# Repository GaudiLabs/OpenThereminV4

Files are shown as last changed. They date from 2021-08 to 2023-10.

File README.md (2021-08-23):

# OpenThereminV4
Open Source Theremin Instrument

Schematics, printed circuit board (PCB) design, bill of materials (BOM) and Arduino UNO compatible software for the OpenTheremin V4

### Open Source Theremin based on the Arduino Platform

OpenTheremin is an arduino based real Therein instrument. The legendary music instrument was invented by Leon Theremin back in 1920. The theremin is played with two antennas, one to control the pitch and one for volume. The electronic shield with two ports to connect those antennas comprises two heterodyne oscillators to measure the distance of the hand to the antenna when playing the instrument. The resulting signal is fed into a AtMega328P microcontroller. After linearization and filtering the circuit generates the instruments sound that is then played through a high quality digital analog audio converter on the board. The characteristics of the sound can be determined by a wave table on the arduino.

For more info on the open source project and on availability of ready made shield see:

http://www.gaudi.ch/OpenTheremin/

### Installation
1. Open up the Arduino IDE
2. Open the File "Open_Theremin_V4.ino"
3. Selecting the correct usb port on Tools -> Serial Port
4. Select the correct arduino board from Tools -> Board
5. Upload the code by clicking on the upload button.

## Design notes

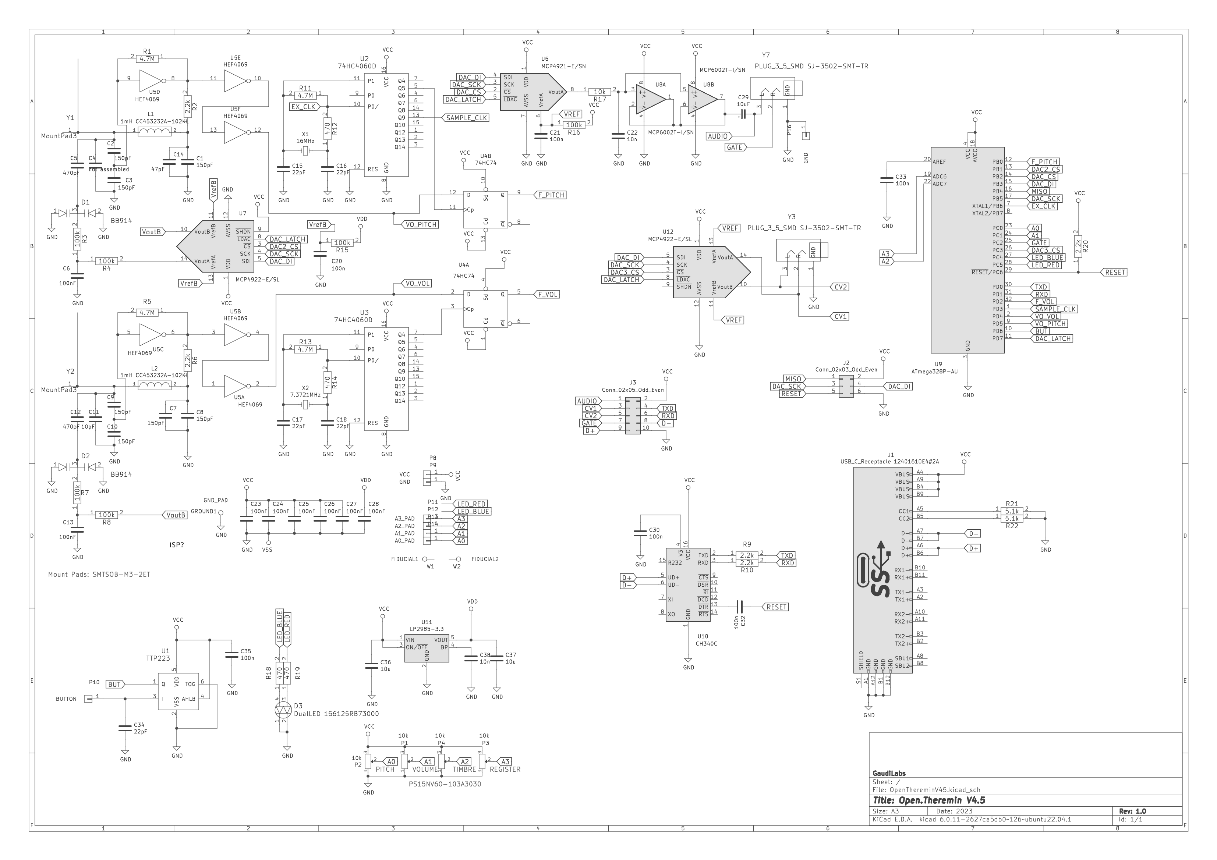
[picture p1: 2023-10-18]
Electronics/OpenThereminV45_Schematic.png

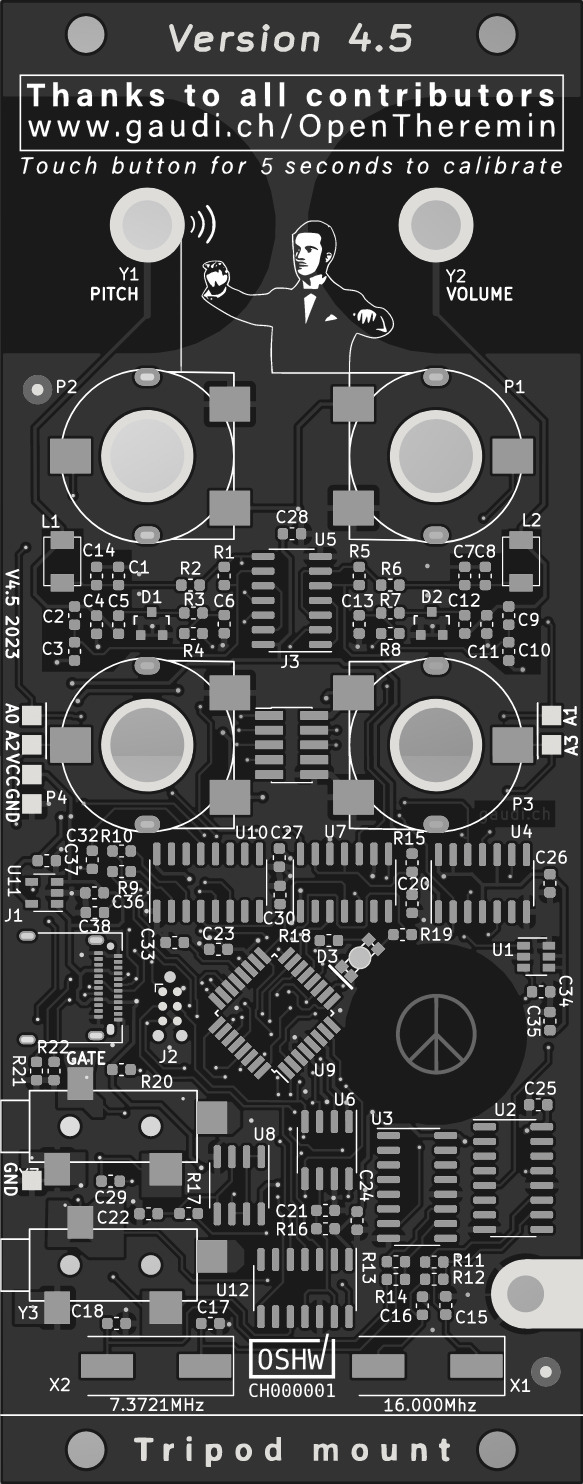
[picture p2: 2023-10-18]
Electronics/OpenThereminV45_PCB_back.png

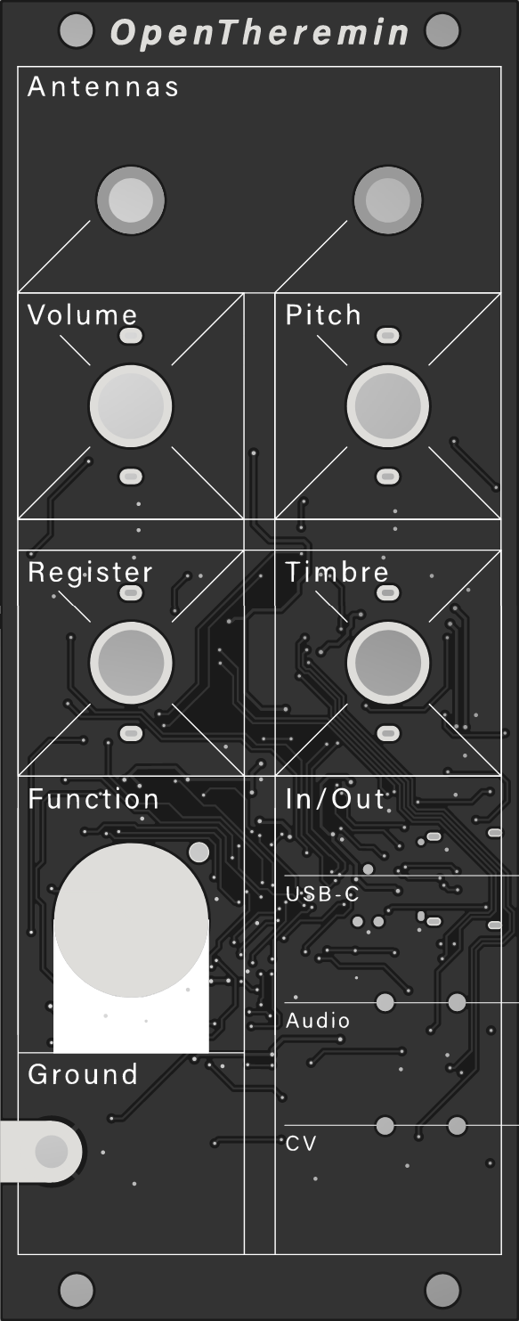
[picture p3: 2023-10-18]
Electronics/OpenThereminV45_PCB_front.png

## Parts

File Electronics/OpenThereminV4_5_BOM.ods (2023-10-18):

 |  |  | OpenTheremin V4.5 BOM (Bill of Materials)
 |  |  |  |  |  | August 5, 2023
Item # | *Ref Des | *Qty | Manufacturer | *Mfg Part # | Description / Value | *Package | Type | Your Instructions / Notes
1 | U1 | 1 | TonTek | TTP223E-BA6 | TonTouch, key touch pad detector IC | SOT-23-6 | SMD
2 | U2,U3 | 2 | Nexperia | 74HC4060D | 14-STG RC BINARY COUNTER | SOIC-16_N | SMD
3 | U4 | 1 | Nexperia | 74HC74D | Flip-Flops DUAL D-TYPE POSITIVE EDGE-TRIG | SOIC-14_N | SMD
4 | U5 | 1 | Nexperia | HEF4069UBT | HEX INVERTER | SOIC-14_N | SMD
5 | U6 | 1 | Microchip Technology | MCP4921T-E/SN | DAC Sgl 12-bit SPI int | SOIC-08_N | SMD
6 | U7, U12 | 2 | Microchip Technology | MCP4922T-E/SL | DAC Dual 12-bit SPI int | SOIC-14_N | SMD
7 | U8 | 1 | Microchip Technology | MCP6002T-I/SN | OpAmp Dual 1.8V 1MHz | SOIC-08_N | SMD
8 | U9 | 1 | Microchip Technology | ATMEGA328P-AU | 8-bit Microcontrollers - MCU 32KB, 20MHz 1.8V-5.5V | TQFP-32_7x7mm_P0.8mm | SMD
9 | U10 | 1 | ETC | CH340C | USB to serial chip | SOIC-16_3.9x9.9mm_P1.27mm | SMD
10 | U11 | 1 | Texas Instruments | LP2985-33DBV | LDO Voltage Regulators 3.3V, 150-mA Low-Noise | SOT-23-5 | SMD
11 | D1,D2 | 2 | Infineon Technologies | BB 914 E6327 | Varactor Diodes 50mA Silicn Variable Capacitance Diode | SOT-23 | SMD
12 | D3 | 1 | Wurth Elektronik | 156125RB73000 | Reverse SMD BiColor LED Blue / Red, WL-SBRW | DualLED | SMD
13 | X1 | 1 | any | Crystals 16.000MHz +/-30ppm 18pF | Crystals | Crystal_HC49-SD_SMD 13.4 x 4.9 x 4.3mm | SMD
14 | X2 | 1 | any | Crystals 7.37280MHz +/-30ppm 18pF | Crystals | Crystal_HC49-SD_SMD 13.4 x 4.9 x 4.3mm | SMD
15 | L1,L2 | 2 | Bourns | CC453232A-102KL | Coil, 1mH UH 10%, 40 Ohms | COIL | SMD
16 | C1,C2,C3,C9,C10,C7,C8 | 7 | any | 150pF 50V NPO 5% | Capacitor | 603 | SMD | MUST BE C0G (NP0)
17 | C5,C12 | 2 | any | 470pF 50V NPO 5% | Capacitor | 603 | SMD | MUST BE C0G (NP0)
18 | C22,C38 | 2 | any | 10nF 16 V X7R 5% | Capacitor | 603 | SMD
19 | C6,C13,C20,C21,C23, C24,C25,C26,C27,C28,C30,C32,C33,C35 | 14 | any | 100nF 25V X7R 10% | Capacitor | 603 | SMD
20 | C29,C36,C37 | 3 | any | 10uF 6.3V X5R 10% | Capacitor | 603 | SMD
21 | C14 | 1 | any | 47pF 50V NPO 5% | Capacitor | 603 | SMD | MUST BE C0G (NP0)
22 | C11 | 1 | any | 10pF 50V NPO 5% | Capacitor | 603 | SMD | MUST BE C0G (NP0)
23 | C4 | 0 | any | NOT ASSEMBLED |  | 603 | SMD
24 | C15,C16,C17,C18,C34 | 5 | any | 22pF 16 V X7R 5% | Capacitor | 603 | SMD | MUST BE C0G (NP0)
25 | R1,R5,R11,R13 | 4 | any | 4.7M OHM 1% | Resistor | 603 | SMD
26 | R12,R14,R18,R19 | 4 | any | 470 OHM 1% | Resistor | 603 | SMD
27 | R17 | 1 | any | 10K OHM 1% | Resistor | 603 | SMD
28 | R3,R4,R7,R8,R15,R16 | 6 | any | 100K OHM 1% | Resistor | 603 | SMD
29 | R2,R6,R9,R10,R20 | 5 | any | 2.2k OHM 1% | Resistor | 603 | SMD
30 | R21,R22 | 2 | any | 5.1k OHM 1% | Resistor | 603 | SMD
31 | Y3, Y7 | 2 | CUI Devices | SJ-3524-SMT-TR | Phone Connectors Audio Jacks, 3.5mm SMD | PLUG3_5_SMD | SMD
32 | P1,P2,P3,P4 | 4 | Amphenol Piher | PS15NV60-103A3030-PM | SMD POT 10K OHM LINEAR | SMD POT | SMD
33 | J1 | 1 | Amphenol Commercial Products | 12401610E4#2A | USB_C_Receptacle_Amphenol_12401610E4-2A | USB_C_Receptacle | SMD
34 | J3 | 1 | Amphenol FCI | 20021521-00010C1LF | 10 Pos, 1.27 MM BTB HEADER SMT TYPE SHROUD | SMD Receptacle | SMD
35 | Y1, Y2 | 2 | PEM | SMTSO-M3-3ET | BRASS SMT STANDOFF M3 L:3MM | Hardware | SMD

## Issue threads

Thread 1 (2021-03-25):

More flexibility on USB/Serial interface design could be nice

MrDham, 2021-03-25:
Hello Urs,

I had a look at this new theremin schematic. It is a very nice idea to merge arduino and schield board in a single one.

I hope that I don't bother you in a too much early or too much late stage of the development, I have just one comment:

As CH340G can't be re-programmed into a MIDI USB port, in order to allow implementation of some additionnal material for a MIDI interface (MIDI DIN connector, ... ), an additionnal free solder pad on TXD could be very nice to have.

Regards

MrDham, 2021-09-10:
It seem that this issue is fixed, isn't it ?

In most recent design, I can see that a new pad is connected to RXD of CH340G wich is equivalent to TXD of ATMEGA 328P -> correct :+1:

GaudiLabs, 2021-12-09:
Yes, we can now do MIDI over serial and real MIDI connector to TX pad.

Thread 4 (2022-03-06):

PCB file is inconsistent with GBR file.

ws786873, 2022-03-06:
PCB file is inconsistent with GBR file. I want to use PCB file to generate SMT positioning, but it seems that PCB file is a semi-finished product. 0603 is a little difficult for me.

GaudiLabs, 2022-03-06:
Hi
Before just accusing me of publishing unfinished files, please tell me who you are and how you can contribute in joining this project. Then please be  specific enough for me to see where you ran into problems. If you just want a working theremin you can buy it here:

gaudishop.ch

Best,
Urs

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
🧪 GaudiLabs LLC
Urs Gaudenz
Email: ***@***.***
www.gaudi.ch

ws786873, 2022-03-06:
Sorry, I just want to make one. I can't seem to contribute anything to the project. Sorry again.

GaudiLabs, 2022-03-06:
The files are designed on the open design software KiCad. You can export Gerber files from thete. If you see inconsistencies with the repo files,  please regenerate the gerber files and fix that
Urs

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
🧪 GaudiLabs LLC
Urs Gaudenz
Email: ***@***.***
www.gaudi.ch

Closed 2022-03-07.

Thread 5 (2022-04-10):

SPI bus breakout

Semptum, 2022-04-10:
Hi,
Is there a place where one can plug onto the SPI bus?
Looking at the PCB layout in KiCAD I can't find a practical place where I could connect something.
I'm looking to add Bluetooth functionality so I thought I would add a secondary board with an ESP32 and a small screen to be able to connect to headphones/speakers and establish an A2DP stream.
Is there a better way to connect the two than soldering a wire onto the atmega's pads?
Best regards

Semptum, 2022-04-10:
Looking more carefully at the schematic (hardware is not my forte), I

Closed 2022-04-10.

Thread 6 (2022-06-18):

Missing technical drawing

8bignic8, 2022-06-18:
Hey, it would be amazing if you could add the scamatics aka the position of all the knobs and so on as a pdf, because I want to make a Kase with a midi output for the teremin. I could mesaure it but I think it would be better if I had the  korrekt positions :).

If it is not possible that is also ok, but it would be a nice to have for the case design :)

greetings nice project

Closed 2023-03-08.

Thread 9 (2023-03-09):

ATmega fuses setting

roman-dvorak, 2023-03-09:
Hello,
is known the correct setting of ATmega fuses? It would be useful to describe it somewhere.

Thank you

GaudiLabs, 2023-03-09:
FUSES

EXTENDED FUSE BYTE (EFUSE):  0xFD
HIGH FUSE BYTE:  0xDE
LOW FUSE BYTE: 0xFF

(Same as Arduino UNO.)

Closed 2023-03-09.

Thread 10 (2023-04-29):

Trouble uploading sketch from Arduino IDE

thedeany, 2023-04-29:
I'm trying to upload a new version to the theremin I just received last week (I'm trying the MIDI implementation, but this issue also occurs if I try to upload the standard version as in this repo), and I'm getting the following error message.
```
Sketch uses 27082 bytes (83%) of program storage space. Maximum is 32256 bytes.
Global variables use 362 bytes (17%) of dynamic memory, leaving 1686 bytes for local variables. Maximum is 2048 bytes.
avrdude: stk500_recv(): programmer is not responding
avrdude: stk500_getsync() attempt 1 of 10: not in sync: resp=0x00
avrdude: stk500_recv(): programmer is not responding
avrdude: stk500_getsync() attempt 2 of 10: not in sync: resp=0x00
avrdude: stk500_recv(): programmer is not responding
avrdude: stk500_getsync() attempt 3 of 10: not in sync: resp=0x00
avrdude: stk500_recv(): programmer is not responding
avrdude: stk500_getsync() attempt 4 of 10: not in sync: resp=0x00
avrdude: stk500_recv(): programmer is not responding
avrdude: stk500_getsync() attempt 5 of 10: not in sync: resp=0x00
avrdude: stk500_recv(): programmer is not responding
avrdude: stk500_getsync() attempt 6 of 10: not in sync: resp=0x00
avrdude: stk500_recv(): programmer is not responding
avrdude: stk500_getsync() attempt 7 of 10: not in sync: resp=0x00
avrdude: stk500_recv(): programmer is not responding
avrdude: stk500_getsync() attempt 8 of 10: not in sync: resp=0x00
avrdude: stk500_recv(): programmer is not responding
avrdude: stk500_getsync() attempt 9 of 10: not in sync: resp=0x00
avrdude: stk500_recv(): programmer is not responding
avrdude: stk500_getsync() attempt 10 of 10: not in sync: resp=0x00
Failed uploading: uploading error: exit status 1
```

I am selecting `Arduino Uno` from the boards list in the IDE, and as far as I am aware a "Programmer" does not need to be selected/the programmer choice doesn't matter in this case.

I have updated to the latest version of the IDE, I have tried multiple USB cables and ports, and I've searched for general solutions to this `avrdude` error, and nothing fixes the issue. Do I need to burn a new bootloader or something? I'm not sure exactly what the process looks like if so.

Any assistance would be appreciated!

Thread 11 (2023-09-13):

Problem with a capacitor in the BOM

emilien-g, 2023-09-13:
Hi,
I think there's maybe a mistake in the BOM
On line 31, for "C15,C16,C17,C18,C19,C31,C34", it's written both "22pF 16 V X7R 5%" and "MUST BE C0G (NP0)"
Thanks a lot for your work !

krokosik, 2024-08-12:
@GaudiLabs @emilien-g I want to order the capacitor, but I'm not sure which variant is right. Which is it?

krokosik, 2024-08-12:
From what I can see in the schematic, these are used for decoupling near the the button, while the others form Pierce Oscillators together with the crystals. I am no expert in audio, but from what I now the C0G are only needed in the LC oscillator, and for the aforementioned applications, the cheaper X7R is sufficient.

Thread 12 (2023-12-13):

Volume ist crcking or bounceing

Kachelhaus, 2023-12-13:
I hear a cracking sound when I mute or unmute the sound and when I increase the volume with the antenna. It is at the point where the volume increases.

GaudiLabs, 2023-12-14:
This might be due to the gate signal on the second audio channel. You can use a mono cable or deactivate the gate signal in the code before uploading.

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
🧪 GaudiLabs LLC
Urs Gaudenz
Email: ***@***.***
www.gaudi.ch

Kachelhaus, 2023-12-14:
Thank you very much,

I overlooked the fact that the gate signal is on the second channel.

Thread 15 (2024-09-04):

tonal distribution

twentyfortysix, 2024-09-04:
Hi, sorry for the question in the issues.. but might be something useful.

Is it possible to define the tonal distribution across the pitch range?

scenario:
The lower tones are bigger therefore has wider hand movement range while the high tones are getting closer and closer and are harder to play as the distance between them is getting smaller.
What would be useful would be to have a chance to alter the values so that the lower tones are closer than are by default and the higher tones are further form one another than are by default.
It might be on a software side as function that would adjust the incoming pitch value by a factor value, the value distribution

python example
```
import numpy as np

def exponential_distribution(arr, factor=1.0):
    """
    Adjust the distribution of numbers in an array to follow an exponential curve.

    Parameters:
    arr (list of float): The input array of numbers.
    factor (float): The factor controlling the steepness of the exponential curve.
                    Values > 1.0 make the curve steeper, values < 1.0 make it shallower.

    Returns:
    list of float: The adjusted array of numbers following an exponential distribution.
    """
    if len(arr) < 2:
        return arr  # No adjustment needed for arrays with less than 2 elements

    # Normalize the input array to the range [0, 1]
    normalized_arr = np.linspace(0, 1, len(arr))

    # Apply the exponential transformation
    exp_arr = (np.exp(normalized_arr * factor) - 1) / (np.exp(factor) - 1)

    # Scale the exponential array back to the original range
    min_value = arr[0]
    max_value = arr[-1]
    adjusted_arr = min_value + exp_arr * (max_value - min_value)

    return adjusted_arr.tolist()

# Example usage
original_array = [0, 1, 2, 3, 4, 5, 6, 7, 8, 9]
factor = 2.0  # Increase the steepness of the exponential curve
adjusted_array = exponential_distribution(original_array, factor)
print("Original array:", original_array)
print("Adjusted array:", adjusted_array)
```

result
```
Original array: [0, 1, 2, 3, 4, 5, 6, 7, 8, 9]
Adjusted array: [0.0, 0.3505431453935727, 0.7883185560546282, 1.3350338825354344, 2.017798699676874, 2.870468769358103, 3.935324821511089, 5.265169097891943, 6.9259436183985335, 9.0]

```

see the value distribution changes across the range, and that what is needed.
The Open theremin would have either a function with a factor value we can change as a number or the better a knob that would allow us to alter the distribution.

As that is the killer feature the PRO Moog theremins used to have, which makes them way more playable as the high notes thanks to the altered pitch value were easier to be played.

twentyfortysix, 2024-09-05:
Completed?
how is that completed? Would be nice to know how it is implemented if that is implemented already.

GaudiLabs, 2024-09-05:
Hi

Thanks for sharing your thoughts for a tonal distribution feature. The micro-controller on the current version is quite loaded already and I don't think it could do the necessary calculations fast enough. You could try of course :-). However I am collecting ideas for a next version with a more speedy processor and will for sure keep this in mind.

Best,
Urs

twentyfortysix, 2024-09-05:
Hi Urs
Just an idea, kinda brute force. What about using the mapping array, similar to wavetable.
Actual value would simply by mapped to whatever is in the mapping array. That way there will be no calculation..

Although it seems that one value processing should not be that expensive.

I have checked the code a bit and it looks like you have some pitch factors already
https://github.com/GaudiLabs/OpenThereminV4/blob/main/Software/Open_Theremin_V4/application.h
the HZ_ADDVAL_FACTOR looks like it would do the trick actually (application.cpp).

```
void Application::hzToAddVal(float hz)
{
  setWavetableSampleAdvance((uint16_t)(hz * HZ_ADDVAL_FACTOR));
}
```

here is a modified version with a exponential factor in the play

```
// Define the exponential factor
const float EXPONENTIAL_FACTOR = 2.0f; // Example value, adjust as needed

void Application::hzToAddVal(float hz)
{
  // Apply exponential transformation
  float transformedHz = pow(hz, EXPONENTIAL_FACTOR);

  // Calculate the sample advance value using the transformed frequency
  setWavetableSampleAdvance((uint16_t)(transformedHz * HZ_ADDVAL_FACTOR));
}
```
see it is easy ;) One variable and here we go, a flexible tonal distribution adjustment I have never been able to adjust on the Moog :)

Well Once the unit arrives I'll give it a go and will fiddle around with the code try what I can do about it.

Btw. I really like the Open theremin Idea and I feel like it is the actual utmost Theremin out there with lot of potential with all the flexibility thanks to the open code.

Closed 2024-09-05.

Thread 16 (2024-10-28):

documentation fault

twentyfortysix, 2024-10-28:
Hi,. sorry to make this as an issue but your captcha on the website correctly recognized me as a robot and a haven't been able to send you this over the form..

There is a wrong link to a wrong cable
https://www.gaudi.ch/OpenTheremin/index.php/opentheremin-v4/midi-interface
which points to a cable with larger pin spacing
https://www.conrad.com/en/p/bkl-electronic-10120668-ribbon-cable-contact-spacing-2-54-mm-10-x-0-08-mm-grey-1-pc-s-2103794.html

While the spacing should be a 1.27mm
something like that maybe https://www.tme.eu/cz/en/details/mikroe-1766/development-kits-accessories/mikroe/flat-cable-with-idc10-1-27mm-pitch-conne/

I just order 2 wrong batch of the cables and I feel I'm not alone :)

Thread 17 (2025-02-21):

hacking away the pitch calculation

tgirod, 2025-02-21:
Hey there. I'm trying to alter the code so the theremin plays on a hard-coded scale, and looking for advices.

Reading the code, I think I should patch something [around here](https://github.com/GaudiLabs/OpenThereminV4/blob/6819b4729de6e0845c20cc2e50181e822b74e7c8/Software/Open_Theremin_V4/application.cpp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)

What I understand from this

        tmpPitch = ((pitchCalibrationBase - pitch_v) + 2048 - (pitchPotValue << 2));
        tmpPitch = min(tmpPitch, 16383);  // Unaudible upper limit just to prevent DAC overflow
        tmpPitch = max(tmpPitch, 0);      // Silence behing zero beat
        setWavetableSampleAdvance(tmpPitch >> registerValue);
        if (tmpPitch != pitch_p)
        { // output new pitch CV value only if pitch value changed (saves runtime resources)
          pitch_p = tmpPitch;

Pitch value is read from the antenna, then recalibrated, then used to move a pointer forward in a wave table.

`tmpPitch` value is bounded to `[0;16383]` after it has been recalibrated, and [hzToAddVal](https://github.com/GaudiLabs/OpenThereminV4/blob/6819b4729de6e0845c20cc2e50181e822b74e7c8/Software/Open_Theremin_V4/application.cpp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) method suggests that it corresponds to a frequency range `[0;7809]` (divinding by HZ_ADDVAL_FACTOR).

Do I understand this correctly?

Now, I'm not sure I understand how your timing works here. I don't see any interrupt, only `mloop` running at full speed. Does it means that adding some branching inside the loop (to compute the wanted pitch) will affect the loop speed, hence the pitch?

Thanks in advance for your insights.

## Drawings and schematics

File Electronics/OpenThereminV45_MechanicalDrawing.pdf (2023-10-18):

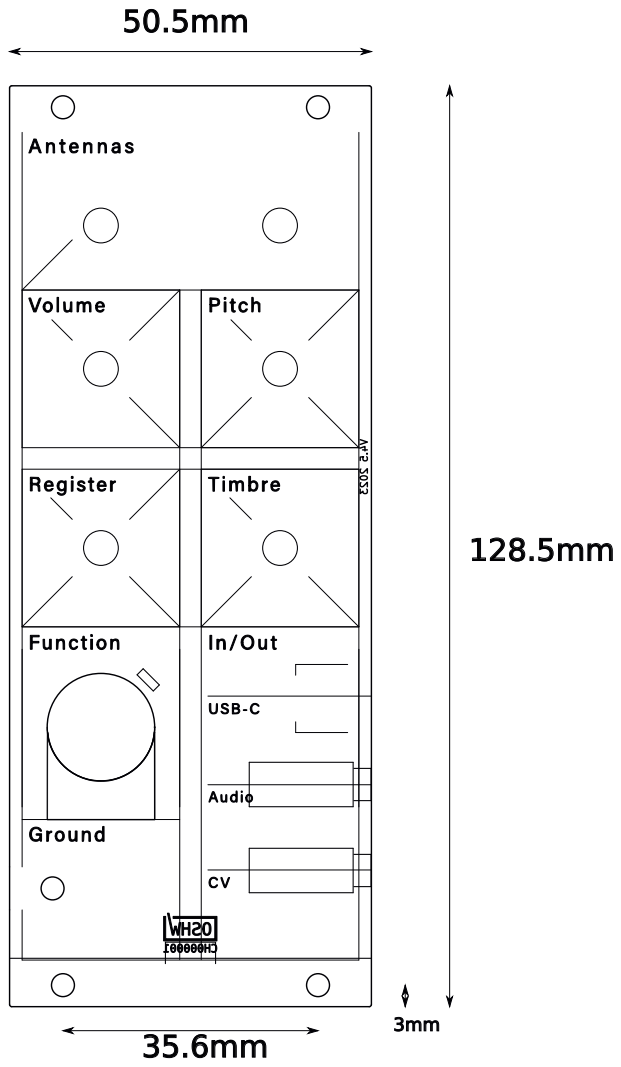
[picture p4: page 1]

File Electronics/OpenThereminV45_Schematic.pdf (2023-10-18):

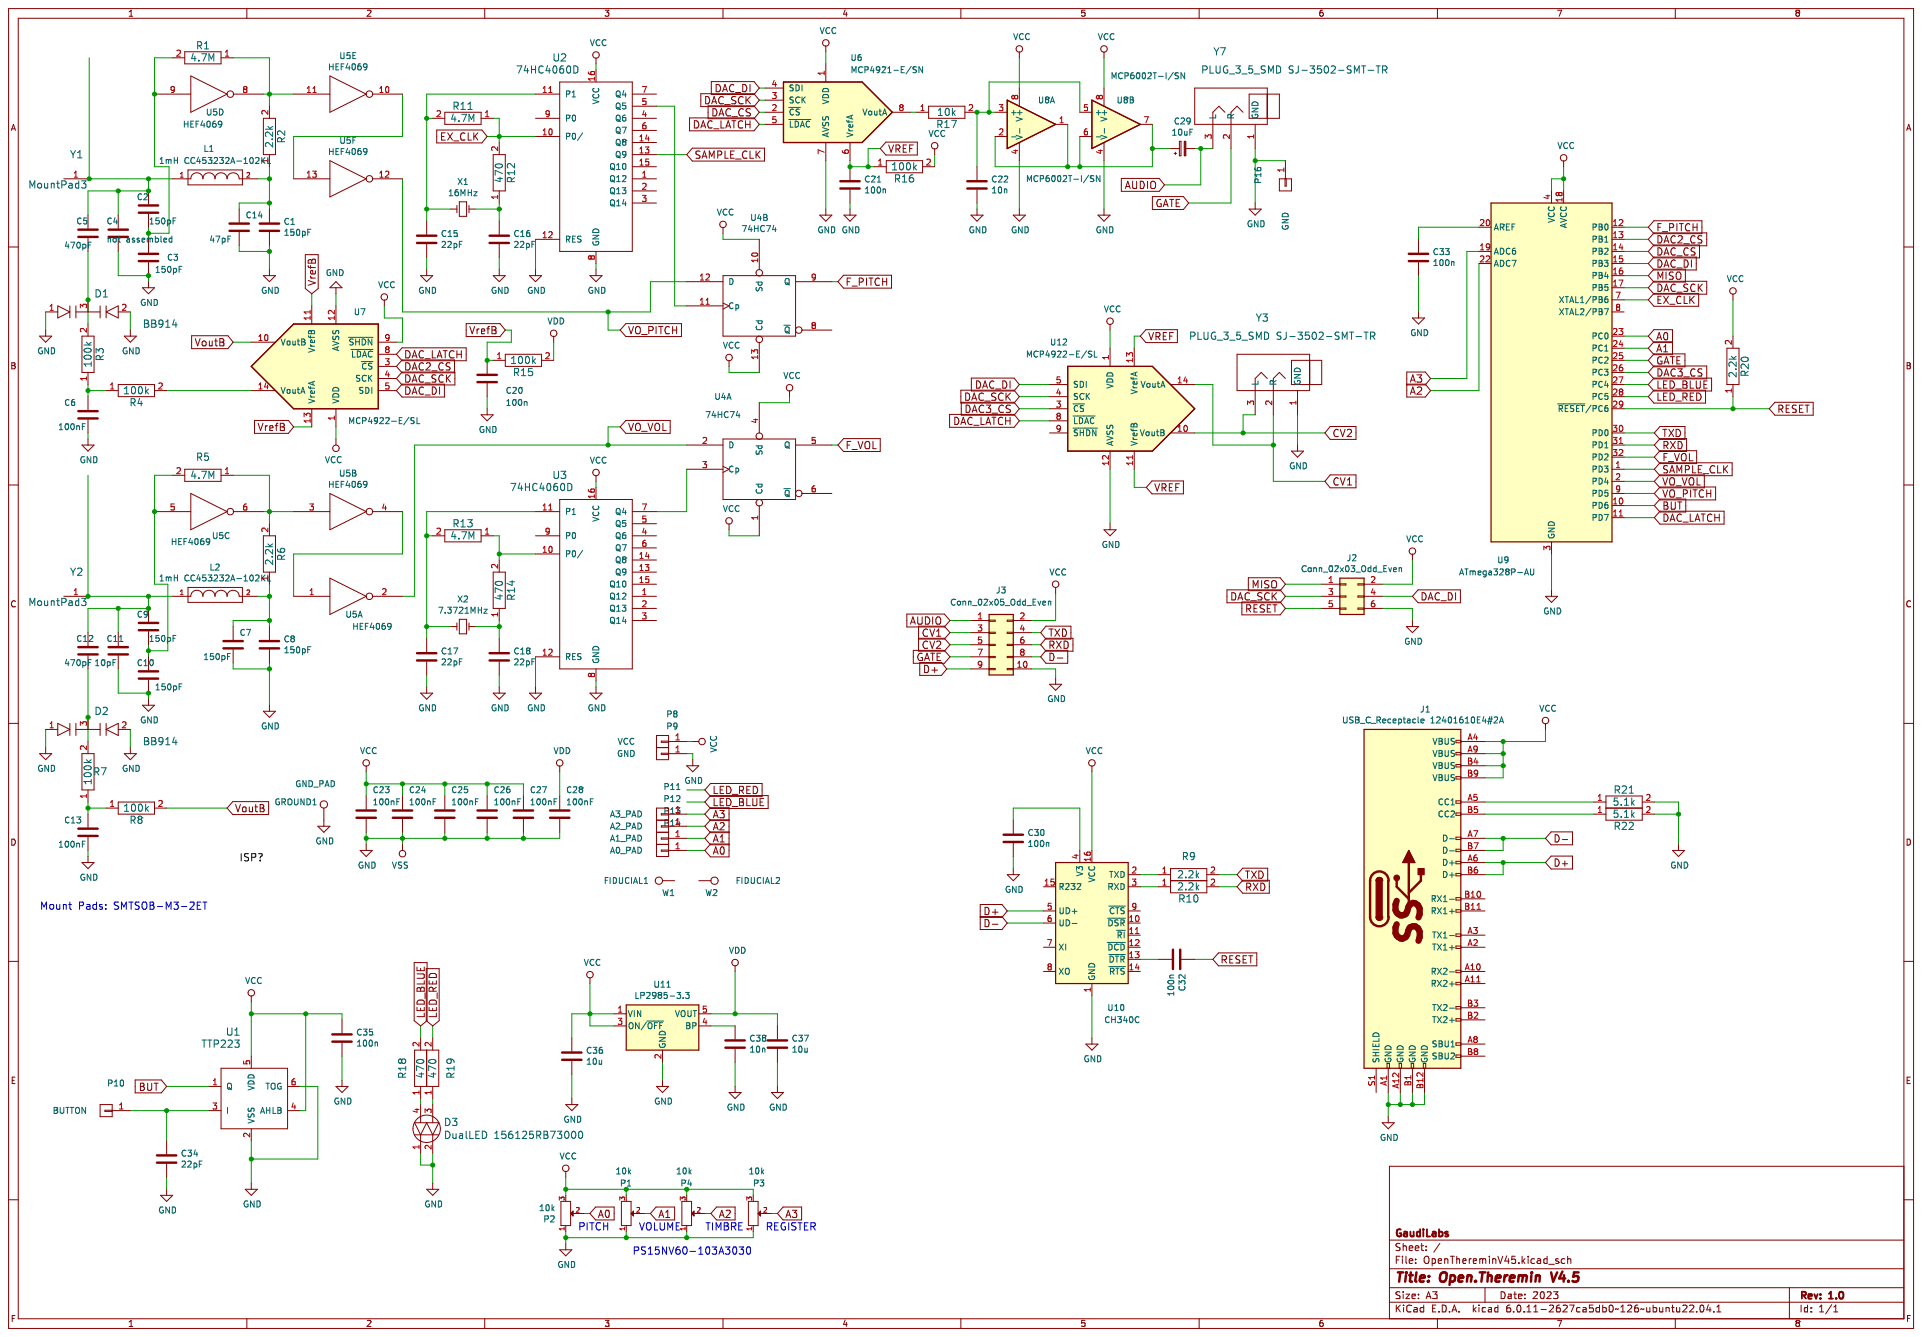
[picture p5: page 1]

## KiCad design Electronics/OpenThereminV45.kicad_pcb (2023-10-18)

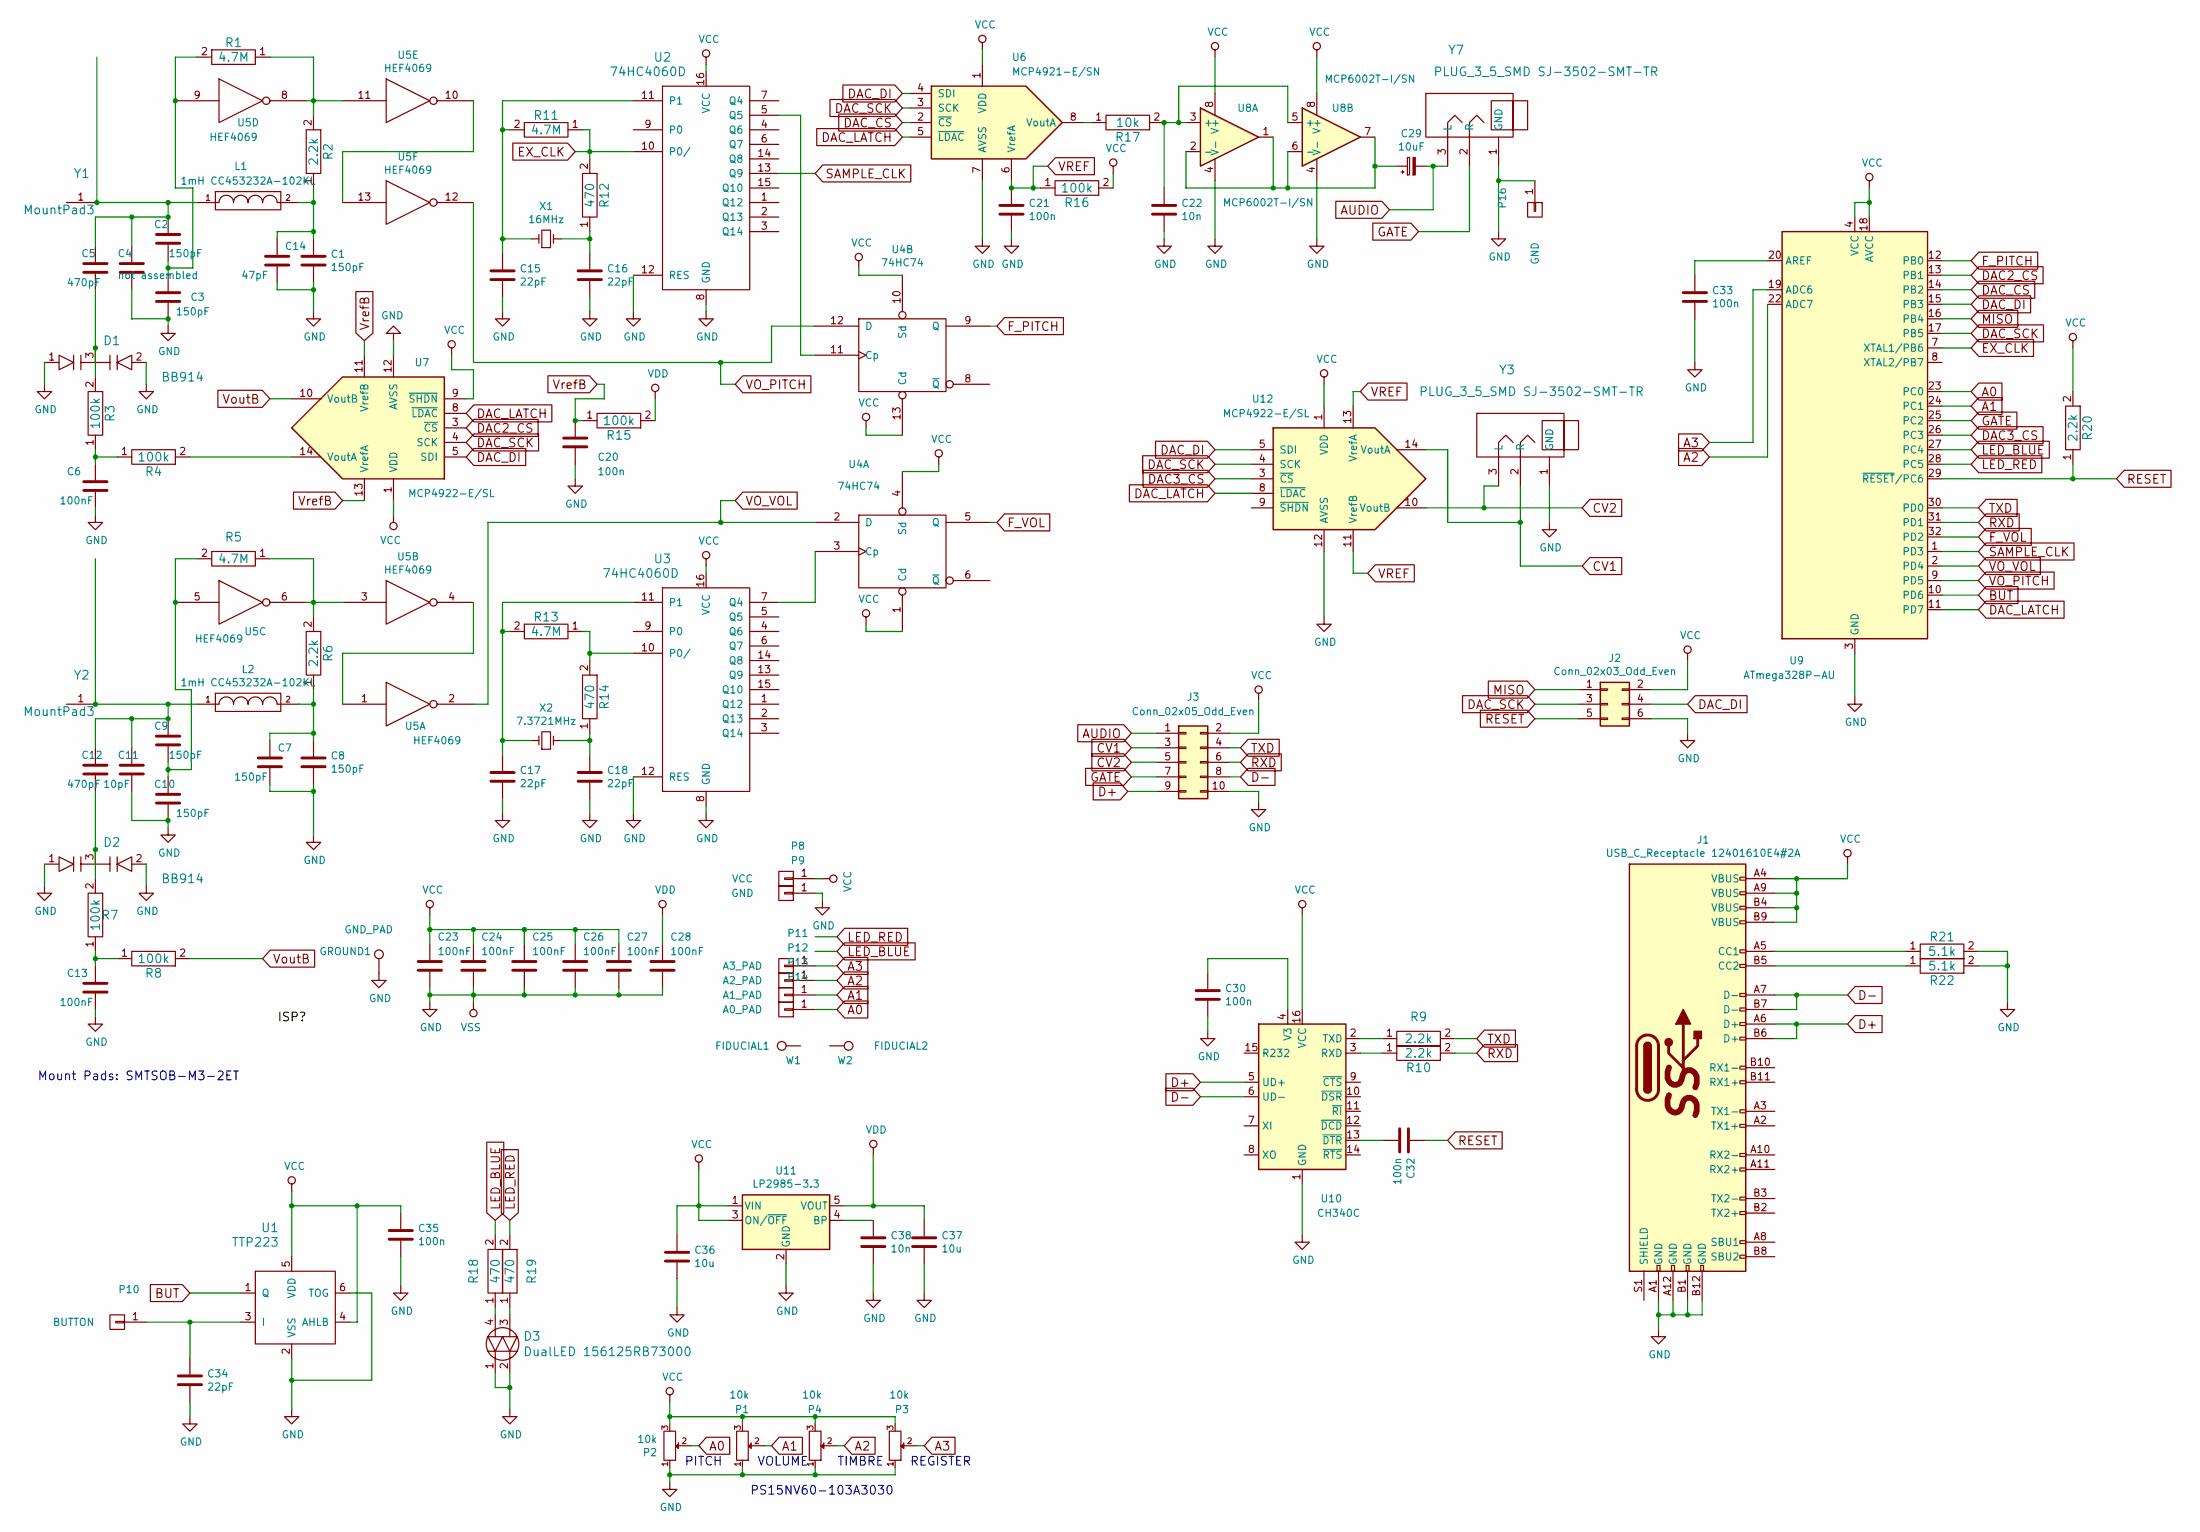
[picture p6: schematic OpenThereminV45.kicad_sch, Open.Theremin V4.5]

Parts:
C1, C2, C3, C7, C8, C9, C10: 150pF; C_0603_1608Metric
C4: not assembled; C_0603_1608Metric
C5, C12: 470pF; C_0603_1608Metric
C6, C13, C23, C24, C25, C26, C27, C28: 100nF; C_0603_1608Metric
C11: 10pF; C_0603_1608Metric
C14: 47pF; C_0603_1608Metric
C15, C16, C17, C18, C34: 22pF; C_0603_1608Metric
C20, C21, C30, C32, C33, C35: 100n; C_0603_1608Metric
C22, C38: 10n; C_0603_1608Metric
C29: 10uF; C_0603_1608Metric
C36, C37: 10u; C_0603_1608Metric
D1, D2: BB914; SOT-23
D3: DualLED 156125RB73000; WL-SBRW
GROUND1: GND_PAD; GNDPad
J1: USB_C_Receptacle 12401610E4#2A; USB_C_Receptacle_Amphenol_12401610E4-2A
J2: Conn_02x03_Odd_Even; Tag-Connect_TC2030-IDC-NL_2x03_P1.27mm_Vertical
J3: Conn_02x05_Odd_Even; PinHeader_2x05_P1.27mm_Vertical_SMD
L1, L2: 1mH CC453232A-102KL; COIL_T
P1, P2, P3, P4: 10k; PS15NV60
P8: VCC; SMD_Pinheader_1_OT_BLANK
P9, P16: GND; SMD_Pinheader_1_OT_BLANK
P10: BUTTON; SensorButton
P11: A3_PAD; SMD_Pinheader_1_OT_BLANK
P12: A2_PAD; SMD_Pinheader_1_OT_BLANK
P13: A1_PAD; SMD_Pinheader_1_OT_BLANK
P14: A0_PAD; SMD_Pinheader_1_OT_BLANK
R1, R5, R11, R13: 4.7M; R_0603_1608Metric
R2, R6, R9, R10, R20: 2.2k; R_0603_1608Metric
R3, R4, R7, R8, R15, R16: 100k; R_0603_1608Metric
R12, R14, R18, R19: 470; R_0603_1608Metric
R17: 10k; R_0603_1608Metric
R21, R22: 5.1k; R_0603_1608Metric
U1: TTP223; SOT-23-6
U2, U3: 74HC4060D; SOIC-16_3.9x9.9mm_P1.27mm
U4: 74HC74; SOIC-14_3.9x8.7mm_P1.27mm
U5: HEF4069; SOIC-14_3.9x8.7mm_P1.27mm
U6: MCP4921-E/SN; SOIC-8_3.9x4.9mm_P1.27mm
U7, U12: MCP4922-E/SL; SOIC-14_3.9x8.7mm_P1.27mm
U8: MCP6002T-I/SN; SOIC-8_3.9x4.9mm_P1.27mm
U9: ATmega328P-AU; TQFP-32_7x7mm_P0.8mm
U10: CH340C; SOIC-16_3.9x9.9mm_P1.27mm
U11: LP2985-3.3; SOT-23-5
W1: FIDUCIAL1; Fiducial_1mm_Dia_2.54mm_Outer_CopperBottom
W2: FIDUCIAL2; Fiducial_1mm_Dia_2.54mm_Outer_CopperBottom
X1: 16MHz; Crystal_SMD_HC49-SD
X2: 7.3721MHz; Crystal_SMD_HC49-SD
Y1, Y2: MountPad3; SMTSOB_M3
Y3, Y7: PLUG_3_5_SMD SJ-3502-SMT-TR; SJ-3502-SMT-TR

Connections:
A0: P2.2, P14.1, U9.23 (PC0)
A1: P1.2, P13.1, U9.24 (PC1)
A2: P4.2, P12.1, U9.22 (ADC7)
A3: P3.2, P11.1, U9.19 (ADC6)
AUDIO: C29.2, J3.1, Y7.3 (L)
BUT: U1.1 (Q), U9.10 (PD6)
CV1: J3.3, U12.14 (VoutA), Y3.2 (R)
CV2: J3.5, U12.10 (VoutB), Y3.3 (L)
D+: J1.A6 (D+), J1.B6 (D+), J3.9, U10.5 (UD+)
D-: J1.A7 (D-), J1.B7 (D-), J3.8, U10.6 (UD-)
DAC2_CS: U7.3 (~CS), U9.13 (PB1)
DAC3_CS: U9.26 (PC3), U12.3 (~CS)
DAC_CS: U6.2 (~CS), U9.14 (PB2)
DAC_DI: J2.4, U6.4 (SDI), U7.5 (SDI), U9.15 (PB3), U12.5 (SDI)
DAC_LATCH: U6.5 (~LDAC), U7.8 (~LDAC), U9.11 (PD7), U12.8 (~LDAC)
DAC_SCK: J2.3, U6.3 (SCK), U7.4 (SCK), U9.17 (PB5), U12.4 (SCK)
EX_CLK: R11.1, R12.2, U2.10 (P0/), U9.7 (XTAL1/PB6)
F_PITCH: U4.9 (Q), U9.12 (PB0)
F_VOL: U4.5 (Q), U9.32 (PD2)
GATE: J3.7, U9.25 (PC2), Y7.2 (R)
GND: C1.2, C3.2, C4.2, C6.2, C7.2, C8.2, C10.2, C11.2, C13.2, C14.2, C15.2, C16.2, C17.2, C18.2, C20.2, C21.2, C22.2, C23.2, C24.2, C25.2, C26.2, C27.2, C28.2, C30.2, C33.2, C34.2, C35.2, C36.2, C37.2, C38.2, D1.1, D1.2, D2.1, D2.2, D3.1, D3.2, GROUND1.1, J1.A1 (GND), J1.A12 (GND), J1.B1 (GND), J1.B12 (GND), J2.6, J3.10, P1.1, P2.1, P3.1, P4.1, P9.1, P16.1, R21.2, R22.2, U1.2 (VSS), U1.6 (TOG), U2.8 (GND), U2.12 (RES), U3.8 (GND), U3.12 (RES), U4.7 (GND), U5.7 (VSS), U6.7 (AVSS), U7.12 (AVSS), U8.4 (V-), U9.3 (GND), U9.5 (GND), U9.21 (GND), U10.1 (GND), U11.2 (GND), U12.12 (AVSS), Y3.1 (GND), Y7.1 (GND)
LED_BLUE: R18.2, U9.27 (PC4)
LED_RED: R19.2, U9.28 (PC5)
MISO: J2.1, U9.16 (PB4)
unnamed: C1.1, C14.1, L1.2, R2.1
unnamed: C2.1, C4.1, C5.1, L1.1, Y1.1
unnamed: C5.2, D1.3, R3.2
unnamed: C6.1, R3.1, R4.1
unnamed: C7.1, C8.1, L2.2, R6.1
unnamed: C9.2, C10.1, R5.2, U5.5
unnamed: C9.1, C11.1, C12.1, L2.1, Y2.1
unnamed: C12.2, D2.3, R7.2
unnamed: C13.1, R7.1, R8.1
unnamed: C15.1, R11.2, U2.11 (P1), X1.1
unnamed: C16.1, R12.1, X1.2
unnamed: C17.1, R13.2, U3.11 (P1), X2.1
unnamed: C18.1, R14.1, X2.2
unnamed: C22.1, R17.2, U8.3 (+), U8.5 (+)
unnamed: C29.1, U8.1, U8.2 (-), U8.6 (-), U8.7
unnamed: C30.1, U10.4 (V3)
unnamed: C32.2, U10.13 (~DTR)
unnamed: C33.1, U9.20 (AREF)
unnamed: C34.1, P10.1, U1.3 (I)
unnamed: C38.1, U11.4 (BP)
unnamed: D3.3, R19.1
unnamed: D3.4, R18.1
unnamed: J1.A5 (CC1), R21.1
unnamed: J1.B5 (CC2), R22.1
unnamed: R1.1, R2.2, U5.8, U5.11
unnamed: C2.2, C3.1, R1.2, U5.9
unnamed: R4.2, U7.14 (VoutA)
unnamed: R5.1, R6.2, U5.3, U5.6
unnamed: R9.1, U10.2 (TXD)
unnamed: R10.1, U10.3 (RXD)
unnamed: R13.1, R14.2, U3.10 (P0/)
unnamed: R17.1, U6.8 (VoutA)
unnamed: U2.5 (Q5), U4.11 (Cp)
unnamed: U3.7 (Q4), U4.3 (Cp)
unnamed: U5.1, U5.4
unnamed: U5.10, U5.13
RESET: C32.1, J2.5, R20.1, U9.29 (~RESET/PC6)
RXD: J3.6, R10.2, U9.31 (PD1)
SAMPLE_CLK: U2.13 (Q9), U9.1 (PD3)
TXD: J3.4, R9.2, U9.30 (PD0)
VCC: C23.1, C24.1, C25.1, C26.1, C27.1, C35.1, C36.1, J1.A4 (VBUS), J1.A9 (VBUS), J1.B4 (VBUS), J1.B9 (VBUS), J2.2, J3.2, P1.3, P2.3, P3.3, P4.3, P8.1, R16.2, R20.2, U1.4 (AHLB), U1.5 (VDD), U2.16 (VCC), U3.16 (VCC), U4.1 (Cd), U4.4 (Sd), U4.10 (Sd), U4.13 (Cd), U4.14 (VCC), U6.1 (VDD), U7.1 (VDD), U7.9 (~SHDN), U8.8 (V+), U9.4 (VCC), U9.6 (VCC), U9.18 (AVCC), U10.16 (VCC), U11.1 (VIN), U11.3 (ON/~OFF), U12.1 (VDD)
VDD: C28.1, C37.1, R15.2, U5.14 (VDD), U11.5 (VOUT)
VO_PITCH: U4.12 (D), U5.12, U9.9 (PD5)
VO_VOL: U4.2 (D), U5.2, U9.2 (PD4)
VREF: C21.1, R16.1, U6.6 (VrefA), U12.11 (VrefB), U12.13 (VrefA)
VoutB: R8.2, U7.10 (VoutB)
VrefB: C20.1, R15.1, U7.11 (VrefB), U7.13 (VrefA)

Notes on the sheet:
REGISTER
VOLUME
TIMBRE
PITCH
PS15NV60-103A3030
Mount Pads: SMTSOB-M3-2ET

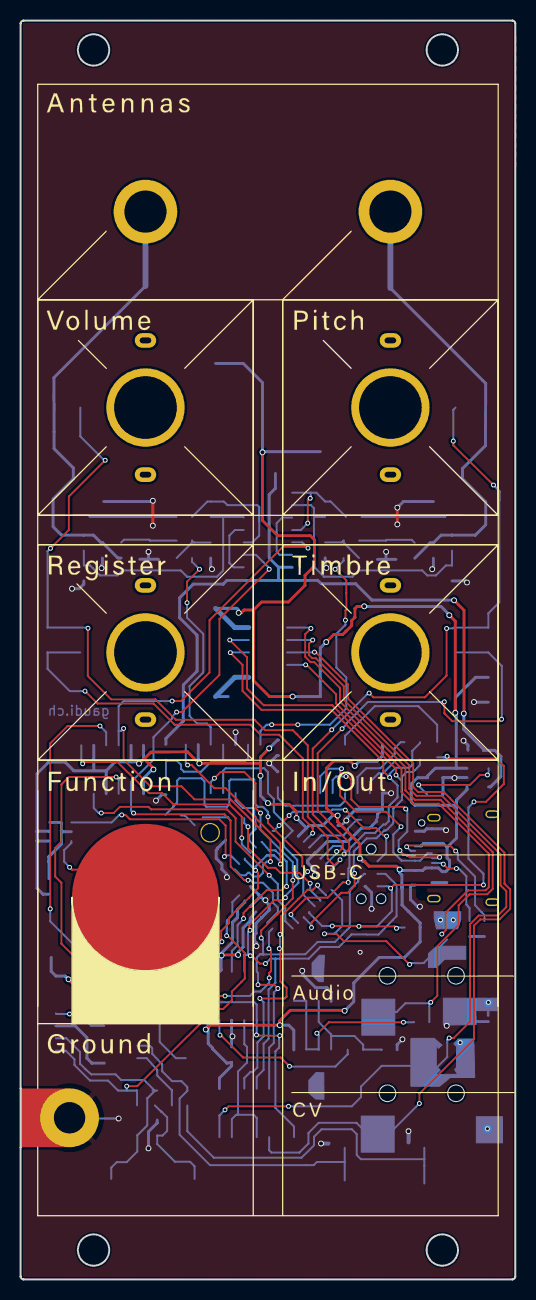
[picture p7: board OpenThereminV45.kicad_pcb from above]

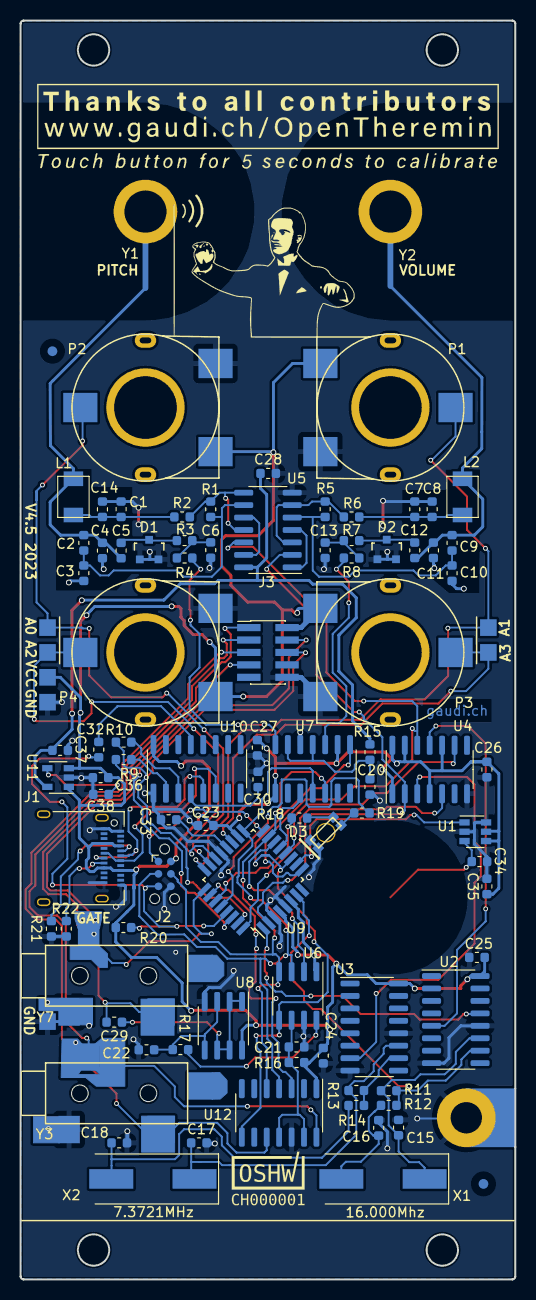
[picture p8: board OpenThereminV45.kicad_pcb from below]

Board: 2 copper layers, 50.5 x 128.5 mm, 99 parts (95 on the bottom side), 71 nets.

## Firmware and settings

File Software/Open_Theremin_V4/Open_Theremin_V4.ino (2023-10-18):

/*
 *  Open.Theremin control software for Arduino UNO
 *  Version 4.0.1
 *  Copyright (C) 2010-2020 by Urs Gaudenz
 *
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
 *  With important contributions by 
 *  David Harvey
 *  Michael Margolis
 *  "Theremingenieur" Thierry Frenkel
 */
 
/**
Building the code
=================
build.h contains #defines that control the compilation of the code

ENABLE_SERIAL - if non-0, the build will include code to write the detected
           pitch to the serial connection every 100 milliseconds. Set serial
           receive baud to 115200

CV_LOG - if non-0, the pitch CV output will follow the Moog/Roland standard 
          of logarithmic 1V/Octave, else it will follow the linear Korg/Yamaha 
          standard with 819Hz/V
           
Structure of the code
=====================
** Open_Theremin_UNO.ino **
This file. Creates and hooks up the application object to the arduino setup()
and loop() callbacks.

** application.h/application.cpp **
Main application object. Holds the state of the app (playing, calibrating), deals
with initialisation and the app main loop, reads pitch and volume changed flags
from the interrupt handlers and sets pitch and volume values which the timer
interrupt sends to the DAC.

** OTPinDefs.h **
Pin definitions for the DAC.

** build.h **
Preprocessor definitions for build (see above).

** hw.h **
Definitions for hardware button and LED.

** ihandlers.h/ihandlers.cpp
Interrupt handler code and volatile variables implementing the communication between
the app and its input/output.

** theremin_sinetable<N>.c **
Wavetable data for a variety of sounds. Switchable via the potentiometer.

** timer.h/timer.cpp **
Definitions and functions for setting delays in tics and in milliseconds

*/

#include "application.h"

Application app;

void setup() {
  app.setup();
}

void loop() {
  app.loop();
}

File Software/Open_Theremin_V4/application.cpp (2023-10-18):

#include "Arduino.h"

#include "application.h"

#include "hw.h"
#include "SPImcpDAC.h"
#include "ihandlers.h"
#include "timer.h"
#include "EEPROM.h"

const AppMode AppModeValues[] = {MUTE, NORMAL};
const int16_t CalibrationTolerance = 15;
const int16_t PitchFreqOffset = 700;
const int16_t VolumeFreqOffset = 700;
const int8_t HYST_VAL = 140;

static int32_t pitchCalibrationBase = 0;
static int32_t pitchCalibrationBaseFreq = 0;
static int32_t pitchCalibrationConstant = 0;
static int32_t pitchSensitivityConstant = 70000;
static int16_t pitchDAC = 0;
static int16_t volumeDAC = 0;
static float qMeasurement = 0;

static int32_t volCalibrationBase = 0;

Application::Application()
  : _state(PLAYING),
    _mode(NORMAL) {};

void Application::setup()
{
#if SERIAL_ENABLED
  Serial.begin(Application::BAUD);
#endif

  HW_LED1_ON;
  HW_LED2_OFF;

  pinMode(Application::BUTTON_PIN, INPUT_PULLUP);
  pinMode(Application::LED_PIN_1, OUTPUT);
  pinMode(Application::LED_PIN_2, OUTPUT);

  digitalWrite(Application::LED_PIN_1, HIGH); // turn the LED off by making the voltage LOW

  SPImcpDACinit();

  EEPROM.get(0, pitchDAC);
  EEPROM.get(2, volumeDAC);

  SPImcpDAC2Asend(pitchDAC);
  SPImcpDAC2Bsend(volumeDAC);

  initialiseTimer();
  initialiseInterrupts();

  EEPROM.get(4, pitchCalibrationBase);
  EEPROM.get(8, volCalibrationBase);
}

void Application::initialiseTimer()
{
  ihInitialiseTimer();
}

void Application::initialiseInterrupts()
{
  ihInitialiseInterrupts();
}

void Application::InitialisePitchMeasurement()
{
  ihInitialisePitchMeasurement();
}

void Application::InitialiseVolumeMeasurement()
{
  ihInitialiseVolumeMeasurement();
}

unsigned long Application::GetQMeasurement()
{
  int qn = 0;

  TCCR1B = (1 << CS10);

  while (!(PIND & (1 << PORTD3)))
    ;
  while ((PIND & (1 << PORTD3)))
    ;

  TCNT1 = 0;
  timer_overflow_counter = 0;
  while (qn < 31250)
  {
    while (!(PIND & (1 << PORTD3)))
      ;
    qn++;
    while ((PIND & (1 << PORTD3)))
      ;
  };

  TCCR1B = 0;

  unsigned long frequency = TCNT1;
  unsigned long temp = 65536 * (unsigned long)timer_overflow_counter;
  frequency += temp;

  return frequency;
}

unsigned long Application::GetPitchMeasurement()
{
  TCNT1 = 0;
  timer_overflow_counter = 0;
  TCCR1B = (1 << CS12) | (1 << CS11) | (1 << CS10);

  delay(1000);

  TCCR1B = 0;

  unsigned long frequency = TCNT1;
  unsigned long temp = 65536 * (unsigned long)timer_overflow_counter;
  frequency += temp;

  return frequency;
}

unsigned long Application::GetVolumeMeasurement()
{
  timer_overflow_counter = 0;

  TCNT0 = 0;
  TCNT1 = 49911;
  TCCR0B = (1 << CS02) | (1 << CS01) | (1 << CS00); // //External clock source on T0 pin. Clock on rising edge.
  TIFR1 = (1 << TOV1);                              //Timer1 INT Flag Reg: Clear Timer Overflow Flag

  while (!(TIFR1 & ((1 << TOV1))))
    ;                                                         // on Timer 1 overflow (1s)
  TCCR0B = 0;                                                 // Stop TimerCounter 0
  unsigned long frequency = TCNT0;                            // get counter 0 value
  unsigned long temp = (unsigned long)timer_overflow_counter; // and overflow counter

  frequency += temp * 256;

  return frequency;
}

AppMode Application::nextMode()
{
  return _mode == NORMAL ? MUTE : AppModeValues[_mode + 1];
}

void Application::loop()
{
  int32_t pitch_v = 0, pitch_l = 0; // Last value of pitch  (for filtering)
  int32_t vol_v = 0, vol_l = 0;    // Last value of volume (for filtering and for tracking)

  uint16_t volumePotValue = 0;
  uint16_t pitchPotValue = 0;
  int registerPotValue, registerPotValueL = 0;
  int wavePotValue, wavePotValueL = 0;
  uint8_t registerValue = 2;
  uint16_t tmpVolume;
  int16_t tmpPitch;
  uint16_t tmpOct;
  uint16_t tmpLog;

mloop: // Main loop avoiding the GCC "optimization"

  pitchPotValue = analogRead(PITCH_POT);
  volumePotValue = analogRead(VOLUME_POT);
  registerPotValue = analogRead(REGISTER_SELECT_POT);
  wavePotValue = analogRead(WAVE_SELECT_POT);

  if ((registerPotValue - registerPotValueL) >= HYST_VAL || (registerPotValueL - registerPotValue) >= HYST_VAL)
    registerPotValueL = registerPotValue;
  if (((wavePotValue - wavePotValueL) >= HYST_VAL) || ((wavePotValueL - wavePotValue) >= HYST_VAL))
    wavePotValueL = wavePotValue;

  vWavetableSelector = wavePotValueL >> 7;

  // New register pot configuration:
  // Left = -1 octave, Center = +/- 0, Right = +1 octave
  if (registerPotValue > 681)
  {
    registerValue = 1;
  }
  else if (registerPotValue < 342)
  {
    registerValue = 3;
  }
  else
  {
    registerValue = 2;
  }

  if (_state == PLAYING && HW_BUTTON_PRESSED)
  {

    resetTimer();
    _state = CALIBRATING;
    _mode = nextMode();

    if (_mode == NORMAL)
    {
      HW_LED1_ON;
      HW_LED2_OFF;
    }
    else
    {
      HW_LED1_OFF;
      HW_LED2_ON;
    };
    // playModeSettingSound();
  }

  if (_state == CALIBRATING && HW_BUTTON_RELEASED)
  {

    _state = PLAYING;
  };

  if (_state == CALIBRATING && timerExpired(65000))
  {
    HW_LED1_ON;
    HW_LED2_ON;

    playStartupSound();

    calibrate_pitch();
    calibrate_volume();

    initialiseTimer();
    initialiseInterrupts();

    playCalibratingCountdownSound();
    calibrate();

    _mode = NORMAL;
    HW_LED2_OFF;

    while (HW_BUTTON_PRESSED)
      ; // NOP
    _state = PLAYING;
  };

#if SERIAL_ENABLED
  if (timerExpired(TICKS_100_MILLIS))
  {
    resetTimer();
    Serial.write(pitch & 0xff); // Send char on serial (if used)
    Serial.write((pitch >> 8) & 0xff);
  }
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

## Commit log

2021-03-23 First layout of V4 juhuu
    [OpenThereminCC-2019-06-01-18-08-36.sch, OpenThereminCC-2019-06-01-19-16-51.sch, OpenThereminCC-2019-06-01-20-19-36.sch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]
2021-03-31 Finalized Prototype design will test soon
    [OpenThereminV4-B_Cu.gbr, OpenThereminV4-B_Mask.gbr, OpenThereminV4-B_Paste.gbr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]
2021-03-31 updated Gerbers
    [OpenThereminV4-B_Cu.gbr, OpenThereminV4-B_Mask.gbr, OpenThereminV4-B_Paste.gbr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]
2021-08-23 PCB V41 with corrections, V4 software first production batch
    [OpenThereminCC-2019-06-01-18-08-36.sch, OpenThereminCC-2019-06-01-19-16-51.sch, OpenThereminCC-2019-06-01-20-19-36.sch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]
2021-09-12 First release with working CVs
    + Added CV processing and output over DAC3a/3b. For details see comments in the code. The pitch CV does not follow the register switch to always use the full 0-5V DAC range and resolution.
    + Removed cadavers from earlier (V3.x and V4.0 beta) experimental CV stuff
    + Added a compiler switch in build.h: CV_LOG. If 1 then, the pitch CV output is ~1V/oct for Moog & Roland Synths (most common standard). If 0 then it is 800Hz/V for Korg and some Yamaha Synths.
2022-01-06 4.0.1
    1. Fixed pitch CV issues with 1V/Oct standard:
    - Glitch at extremely low frequencies
    - Continuity problems (voltage jumps)
    2. Improved overall performance
    3. Added GATE signal with load sending
    [Open_Theremin_V4.ino, application.cpp, application.h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]
2023-10-18 OpenTheremin Version 4.5 new amazing breakout connector
    [OpenThereminV4-B_Cu.gbr, OpenThereminV4-B_Mask.gbr, OpenThereminV4-B_Paste.gbr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]
2023-10-18 Corrected Pos Numbers V4.5
    [OpenThereminV4_5_BOM.ods]

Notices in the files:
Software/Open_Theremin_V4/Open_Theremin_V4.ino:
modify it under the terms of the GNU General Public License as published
